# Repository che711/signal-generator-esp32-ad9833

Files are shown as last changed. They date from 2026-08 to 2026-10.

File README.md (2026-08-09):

# DDS Signal Generator — ESP32 + AD9833 with Web UI



A compact, standalone function generator built with an ESP32 microcontroller
and the AD9833 DDS module. Controlled via a rotary encoder or a built-in
web interface, with status shown on a 0.96" SSD1306 OLED screen.
Settings (frequency, waveform, step) are persisted to flash (NVS) and
restored on boot.

---

## Features

| Feature | Details |
|---|---|
| Frequency range | **0.1 Hz – 12 MHz** |
| Frequency resolution | **0.1 Hz** |
| Waveforms | Sine, Triangle, Square, Square/2 |
| Frequency steps | 0.1 Hz / 1 Hz / 10 Hz / 100 Hz / 1 kHz / 10 kHz / 100 kHz / 1 MHz |
| Acceleration | Fast encoder spin = 10× bigger step |
| Web interface | Embedded single-page UI: set frequency/waveform/step, sweep control, curl cheatsheet, live system stats |
| Sweep | Linear / logarithmic frequency sweep, 0.2 s – 1 h, phase-continuous |
| Output enable | Mute button (web/API): DDS sleep, settings kept, state survives reboot |
| Addressing | IP address shown on the OLED at boot; optional mDNS alias `http://dds-gen.local` |
| Persistence | Auto-save to NVS 5 s after the last change + manual save from web UI |
| WiFi watchdog | Automatic reconnect if the connection drops |
| Display | SSD1306 128×64 OLED (I2C) |
| Control | KY-040 rotary encoder (interrupt-driven quadrature decoder) |
| Output | BNC connector (50 Ω) |
| Power | 5V SMPS + LC filter |

---

## Controls

### Rotary encoder

| Action | Result |
|---|---|
| Rotate encoder | Increase / decrease frequency by current step |
| Fast rotation | Step × 10 acceleration |
| Short press | Cycle waveform (SINE → TRI → SQR → SQR/2) |
| Long press (>0.8s) | Cycle frequency step decade |

### Web interface

Open `http://<device-ip>` — the IP is shown on the OLED at boot and printed
to the serial monitor. The page lets you type an exact frequency, pick the
waveform and step, nudge the frequency by the current step, save settings to
memory, and shows live system stats (RSSI, CPU load, RAM, chip temperature,
uptime).

> **mDNS (`http://dds-gen.local`) is a convenience, not a guarantee.** It
> depends on both the client OS and the router: many consumer routers do not
> forward mDNS between wired and wireless clients or across guest/VLAN
> networks, and some block multicast entirely. Windows needs Bonjour or
> Windows 10 1803+; Android support is patchy. If `.local` does not resolve,
> use the IP address — it always works. For scripts and automation, prefer
> the IP (or a DHCP reservation for it) over the hostname.

HTTP API used by the page (usable from scripts too):

| Endpoint | Effect |
| --- | --- |
| `GET /status` | JSON: frequency, waveform, step + system stats |
| `GET /set/freq?v=<hz>` | Set frequency (0.1 – 12 000 000 Hz) |
| `GET /set/wave?v=<name>` | Waveform: `sine`, `tri`, `sqr`, `sqr2` (legacy `0`-`3` accepted) |
| `GET /set/step?v=<size>` | Encoder step, Hz added per click: `0.1`,`1`,`10`,`100`,`1k`,`10k`,`100k`,`1m` (legacy `0`-`7`) |
| `GET /set/out?v=<0\|1>` | Output enable: `0` mutes the DDS (sleep, ~0 V out), `1` restores the selected waveform |
| `GET /save` | Persist current settings to NVS |
| `GET /reboot` | Save settings, then restart the device (`ESP.restart()`) |
| `GET /sweep/start?f0=&f1=&t=&mode=` | Frequency sweep f0 → f1 Hz over `t` seconds, `mode` = `lin` \| `log` |
| `GET /sweep/stop` | Stop sweep mid-run: frequency stays at its current value. A sweep that finishes on its own returns to the pre-sweep frequency |

Every `/set/*` and `/sweep/*` endpoint replies with the same JSON as `/status`,
reflecting the state actually applied (values are clamped to valid ranges).

<details>
<summary><b>curl examples</b> — scripts, Robot Framework, lab automation</summary>

Replace `192.168.1.45` with your device's IP (a DHCP reservation on the
router keeps it stable). `dds-gen.local` also works where mDNS is available.

```bash
DDS=192.168.1.45

# Device state: frequency, waveform, sweep, RSSI, heap, uptime
curl http://$DDS/status

# 10 kHz sine
curl "http://$DDS/set/freq?v=10000"
curl "http://$DDS/set/wave?v=sine"   # sine | tri | sqr | sqr2

# Log sweep 10 Hz -> 100 kHz over 10 s (Bode plot on the scope)
curl "http://$DDS/sweep/start?f0=10&f1=100000&t=10&mode=log"
curl http://$DDS/sweep/stop

# Persist settings to NVS
curl http://$DDS/save
```

Robot Framework setup example:

```robotframework
*** Settings ***
Library    RequestsLibrary

*** Variables ***
${DDS_HOST}    http://192.168.1.45

*** Keywords ***
Set Reference Signal
    [Arguments]    ${freq}    ${wave}=sine
    GET    ${DDS_HOST}/set/freq    params=v=${freq}
    GET    ${DDS_HOST}/set/wave    params=v=${wave}
```

</details>

---

## Hardware

| Component | Description |
|---|---|
| ESP32 DevKit / Super Mini | Main controller |
| AD9833 module | DDS signal generator (SPI) |
| SSD1306 0.96" | OLED display (I2C) |
| KY-040 | Rotary encoder with push button |
| 5V 1A SMPS | Power supply (barrel jack 5.5×2.1 mm) |
| LC filter | Suppresses switching noise from SMPS |
| BNC socket (isolated) | Output connector |
| 100 Ω resistor | Series protection on BNC output |
| RG58 coax cable + BNC plugs | Output cable to oscilloscope |

---

## Wiring

See [wiring.md](wiring.md) for full pin mapping and ASCII schematic.

### Quick reference (ESP32 DevKit)

```
AD9833  CLK  → GPIO 18
AD9833  DAT  → GPIO 23
AD9833  FSYNC→ GPIO  5

OLED    SDA  → GPIO 21
OLED    SCL  → GPIO 22

KY-040  CLK  → GPIO 34
KY-040  DT   → GPIO 35
KY-040  SW   → GPIO 32

AD9833 OUT → [100Ω] → BNC centre
AD9833 GND          → BNC shell
```

All pins are defined in [src/config.h](src/config.h).

---

## Configuration

Before flashing, edit [src/config.h](src/config.h):

```c
#define WIFI_SSID      "YourNetwork"
#define WIFI_PASSWORD  "YourPassword"
#define MDNS_HOSTNAME  "dds-gen"      // optional alias → http://dds-gen.local
```

`MDNS_HOSTNAME` only sets up the optional `.local` alias; the device is
always reachable by IP regardless of whether mDNS resolves on your network.

If WiFi is unavailable the generator still works standalone with the
encoder and OLED.

> Don't commit real WiFi credentials to a public repository.

---

## Build & Flash

### PlatformIO (recommended)

The project uses the [pioarduino](https://github.com/pioarduino/platform-espressif32)
platform (Arduino core 3.x / ESP-IDF 5.x); dependencies are resolved
automatically from `platformio.ini`.

```bash
git clone https://github.com/che711/signal-generator-esp32-ad9833
cd signal-generator-esp32-ad9833
pio run --target upload
pio device monitor
```

### Arduino IDE

1. Install ESP32 board support (arduino-esp32 core 3.x)
2. Install libraries:
   - `AD9833` by Rob Tillaart
   - `U8g2` by olikraus
3. Copy the contents of `src/` into a sketch (rename `main.cpp` to the sketch `.ino`)
4. Select board: **ESP32 Dev Module**
5. Upload

---

## Project Structure

```
signal-generator-esp32-ad9833/
├── src/
│   ├── main.cpp          # Setup & main loop, autosave logic
│   ├── config.h          # Pins, WiFi credentials, timings
│   ├── generator.h/.cpp  # AD9833 wrapper (frequency, waveform, step, NVS)
│   ├── encoder.h/.cpp    # KY-040 encoder (ISR quadrature decoder, debounced button)
│   ├── display.h/.cpp    # SSD1306 OLED screens
│   └── webui.h/.cpp      # WiFi, web server, mDNS, embedded HTML UI
├── wiring.md             # Full wiring guide + ASCII schematic
├── platformio.ini
└── README.md
```

---

## Display Layout

```
┌────────────────────────┐
│ WAVE: SINE         [W] │  ← inverted top bar, [W] = WiFi connected
├────────────────────────┤
│      1.000 kHz         │  ← large frequency (centred)
├────────────────────────┤
│ STP: 1kHz              │
│ NET: MyNetwork         │  ← SSID
│ IP:  192.168.1.45      │  ← web UI address
└────────────────────────┘
```

---

## Output Notes

- AD9833 output amplitude: ~0.65 Vpp (sine/triangle)
- For higher amplitude add an op-amp stage (e.g. AD8051, TL071)
- Square wave output: up to ~3V logic level
- Add a 100 Ω series resistor on the BNC output to prevent damage on short circuit
- Use 50 Ω coax (RG58) for best signal integrity above 1 MHz

---

## Serial Monitor

At 115200 baud the device prints events:

```
[DDS] Booting...
[GEN] Settings loaded from NVS
[GEN] freq=1000.00Hz wave=0 step=4
[WiFi] Connecting to SkyNet....
[WiFi] IP: 192.168.1.45
[mDNS] http://dds-gen.local
[Web] http://192.168.1.45
[DDS] Ready
[ENC] CW → 2000.00 Hz
[BTN] wave → TRI
[Web] freq → 5000.00 Hz
[GEN] Settings saved to NVS
```

---

## License

MIT License — free for personal and commercial use.

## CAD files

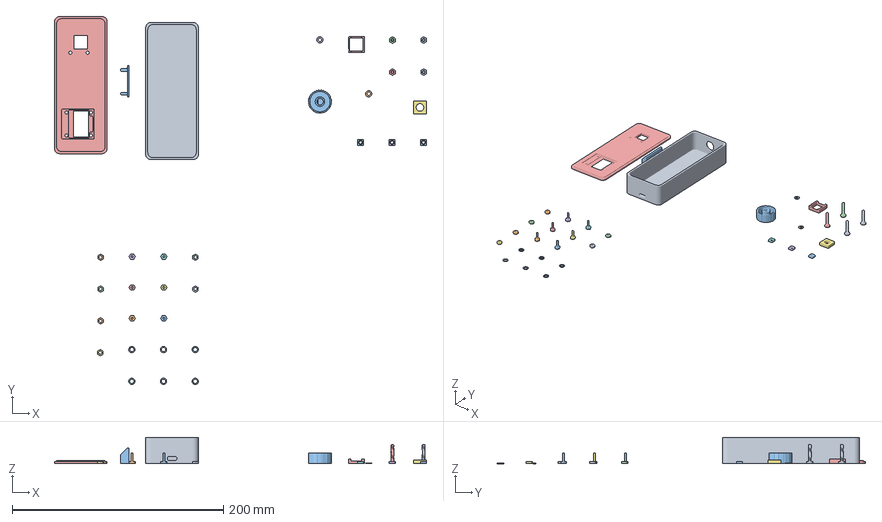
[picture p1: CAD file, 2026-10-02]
docs/Signal_generator_case.3mf
352.3 x 348.4 x 25.0 mm
signal_generator_case.stl_6 x 7
signal_generator_case.stl
signal_generator_case.stl_7 x 7
Amazing Snicket-Bombul (1).stl_2
M3 square nut.stl x 3
Amazing Snicket-Bombul (1).stl_4
M3 washer.stl x 2
webradio_button2.stl
M3x16.stl x 4
Assembly x 6

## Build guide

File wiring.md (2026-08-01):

# Wiring Guide

## Power

```
230V AC → [5V 1A SMPS] → [LC Filter] → 5V rail
                                          │
                              ┌───────────┼──────────────┐
                           ESP32        AD9833        SSD1306
                          (5V/VIN)    (3.3V via      (3.3V via
                                       ESP32)         ESP32)
```

## ESP32 → AD9833 (SPI / HSPI)

| ESP32 Pin | AD9833 Pin | Description |
|---|---|---|
| GPIO 18 | CLK | SPI clock |
| GPIO 23 | DAT | SPI data (MOSI) |
| GPIO  5 | FSYNC | Chip select (CS)  |
| 3.3V | VCC | Power |
| GND | GND | Ground |

> **Note:** AD9833 MISO not used. FSYNC is active-LOW chip select.

## ESP32 → SSD1306 OLED (I2C)

| ESP32 Pin | SSD1306 Pin | Description |
|---|---|---|
| GPIO 21 | SDA | I2C data |
| GPIO 22 | SCL | I2C clock |
| 3.3V | VCC | Power |
| GND | GND | Ground |

> Default I2C address: `0x3C`. Some modules use `0x3D`.
> Check with I2C scanner if display is blank.

## ESP32 → KY-040 Encoder

| ESP32 Pin | KY-040 Pin | Description |
|---|---|---|
| GPIO 34 | CLK | Rotation clock (input-only) |
| GPIO 35 | DT | Rotation data  (input-only) |
| GPIO 32 | SW | Button |
| 3.3V | + | Power |
| GND | GND | Ground |

> GPIO 34 and 35 are **input-only** on ESP32 — no internal pull-up.
> KY-040 has its own pull-up resistors on board, so this is fine.

## BNC Output

| AD9833 Pin | BNC Jack |
|---|---|
| OUT | Centre pin (signal) |
| GND | Shell (ground) |

> Add a **100 Ω series resistor** between AD9833 OUT and BNC centre
> to protect against short circuits.

## Full Schematic (ASCII)

```
                    ┌──────────────────────────────────────┐
   5V ──────────────┤VIN                              GPIO18├──── AD9833 CLK
   GND ─────────────┤GND                              GPIO23├──── AD9833 DAT
                    │                                 GPIO5 ├──── AD9833 FSYNC
                    │                                       │
                    │         ESP32 DevKit            GPIO21├──── OLED SDA
                    │                                 GPIO22├──── OLED SCL
                    │                                       │
                    │                                 GPIO34├──── KY-040 CLK
                    │                                 GPIO35├──── KY-040 DT
                    │                                 GPIO32├──── KY-040 SW
                    │                                       │
                    │   3.3V ─┬──────────────────────       │
                    │         ├── AD9833 VCC                 │
                    │         └── OLED VCC                  │
                    └──────────────────────────────────────┘

AD9833 OUT ──[100Ω]──── BNC centre pin
AD9833 GND ─────────── BNC shell
```

## ESP32 Super Mini Pin Mapping

If using **ESP32 Super Mini** (C3), note it has **no hardware DAC**.
The AD9833 SPI still works — update pin numbers in `src/config.h`:

| Function | DevKit | Super Mini |
|---|---|---|
| SPI SCK  | 18 | 4 |
| SPI MOSI | 23 | 6 |
| SPI CS | 5 | 7 |
| I2C SDA  | 21 | 8 |
| I2C SCL  | 22 | 9 |
| ENC CLK  | 34 | 2 |
| ENC DT | 35 | 3 |
| ENC SW | 32 | 10 |

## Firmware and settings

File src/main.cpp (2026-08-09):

#include <Arduino.h>
#include "generator.h"
#include "encoder.h"
#include "display.h"
#include "webui.h"

// ── Globals ───────────────────────────────────────────────
// The mutex guards SignalGenerator against concurrent access
// from the UI task (core 1) and the web task (core 0)
SemaphoreHandle_t genMutex;

SignalGenerator gen;
Encoder         enc;
Display         disp;
WebUI*          web;   // pointer — constructed after the mutex exists

// ── Web task on core 0 ────────────────────────────────────
void webTask(void* param) {
    web->begin();

    for (;;) {
        web->handle();
        web->checkWiFi();
        web->updateCpuLoad();
        vTaskDelay(pdMS_TO_TICKS(1));   // yield to the scheduler
    }
}

// ── setup ─────────────────────────────────────────────────
void setup() {
    Serial.begin(115200);
    Serial.println("[DDS] Booting...");

    // Create the mutex first — before anything touches gen
    genMutex = xSemaphoreCreateMutex();

    disp.begin();

    // gen.begin() talks to SPI and NVS; the web task is not running yet,
    // so it is safe to call without taking the mutex
    gen.begin();
    enc.begin();

    disp.drawConnecting(WIFI_SSID);

    // Create the WebUI with the mutex and start its task on core 0
    web = new WebUI(gen, genMutex);
    xTaskCreatePinnedToCore(
        webTask,
        "webTask",
        TASK_WEB_STACK,
        nullptr,
        TASK_WEB_PRIORITY,
        nullptr,
        TASK_WEB_CORE
    );

    // Give webTask a moment to bring up WiFi before entering the main loop
    uint32_t waitStart = millis();
    while (!web->isConnected() && millis() - waitStart < WIFI_CONNECT_TIMEOUT_MS + 1000)
        delay(100);

    if (web->isConnected()) {
        disp.drawIP(web->ipAddress());
        delay(3000);
    }

    Serial.println("[DDS] Ready");
}

// ── loop — UI on core 1 ───────────────────────────────────
// Web/WiFi/CPU are serviced by webTask on core 0
static bool     needRedraw = true;
static uint32_t lastSaveMs = 0;
static uint32_t lastDrawMs = 0;

void loop() {
    // Changes made from the web UI must also refresh the OLED and
    // restart the autosave timer
    if (web->consumeChanged()) {
        needRedraw = true;
        lastSaveMs = millis();
    }

    // Sweep: each tick moves the frequency. sweepActive() is read without
    // the mutex — it is a lone bool, worst case is one extra/late take
    if (gen.sweepActive()) {
        if (xSemaphoreTake(genMutex, pdMS_TO_TICKS(5)) == pdTRUE) {
            if (gen.sweepTick(millis())) needRedraw = true;
            xSemaphoreGive(genMutex);
        }
    }

    bool changed = false;
    EncoderEvent ev = enc.poll();

    switch (ev) {
        case ENC_CW: {
            int m = enc.isFast() ? ACCEL_MULTIPLIER : 1;
            if (xSemaphoreTake(genMutex, pdMS_TO_TICKS(10)) == pdTRUE) {
                for (int i = 0; i < m; i++) gen.stepUp();
                Serial.printf("[ENC] CW → %.2f Hz\n", gen.getFrequency());
                xSemaphoreGive(genMutex);
            }
            changed = true;
            break;
        }
        case ENC_CCW: {
            int m = enc.isFast() ? ACCEL_MULTIPLIER : 1;
            if (xSemaphoreTake(genMutex, pdMS_TO_TICKS(10)) == pdTRUE) {
                for (int i = 0; i < m; i++) gen.stepDown();
                Serial.printf("[ENC] CCW → %.2f Hz\n", gen.getFrequency());
                xSemaphoreGive(genMutex);
            }
            changed = true;
            break;
        }
        case ENC_CLICK:
            if (xSemaphoreTake(genMutex, pdMS_TO_TICKS(10)) == pdTRUE) {
                gen.nextWave();
                Serial.printf("[BTN] wave → %s\n", gen.waveLabel());
                xSemaphoreGive(genMutex);
            }
            changed = true;
            break;
        case ENC_LONG_CLICK:
            if (xSemaphoreTake(genMutex, pdMS_TO_TICKS(10)) == pdTRUE) {
                gen.nextStep();
                Serial.printf("[BTN] step → %s\n", gen.stepLabel());
                xSemaphoreGive(genMutex);
            }
            changed = true;
            break;
        default:
            break;
    }

    if (changed) {
        needRedraw = true;
        lastSaveMs = millis();
    }

    // Autosave AUTOSAVE_MS after the last change
    if (lastSaveMs > 0 && millis() - lastSaveMs > AUTOSAVE_MS) {
        if (xSemaphoreTake(genMutex, pdMS_TO_TICKS(50)) == pdTRUE) {
            gen.saveSettings();
            xSemaphoreGive(genMutex);
        }
        lastSaveMs = 0;
    }

    // Redraw at ~30 fps, and only when something changed
    uint32_t now = millis();
    if (needRedraw && now - lastDrawMs > 33) {
        // Snapshot the state under the mutex, then draw without it:
        // sendBuffer() over I2C takes ~22 ms, far too long to hold the
        // mutex while the web task on core 0 may want it.
        String freqStr, waveStr, stepStr;
        if (xSemaphoreTake(genMutex, pdMS_TO_TICKS(10)) == pdTRUE) {
            freqStr = gen.freqLabel();
            // Output disabled — show OFF instead of the waveform
            waveStr = gen.getOutput() ? gen.waveLabel() : "OFF";
            stepStr = gen.stepLabel();
            xSemaphoreGive(genMutex);

            disp.drawMain(
                freqStr,
                waveStr.c_str(),
                stepStr.c_str(),
                web->isConnected(),
                String(WIFI_SSID),
                web->ipAddress()
            );
            lastDrawMs = now;
            needRedraw = false;
        }
        // mutex not acquired → needRedraw stays true, redraw next iteration
    }

    // Short delay so we do not hog core 1
    vTaskDelay(pdMS_TO_TICKS(5));
}

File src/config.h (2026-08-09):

#pragma once

// ── Wi-Fi ─────────────────────────────────────────────────
#define WIFI_SSID      "SkyNet"
#define WIFI_PASSWORD  "password"

// ── Web server ────────────────────────────────────────────
#define WEB_PORT                80
#define MDNS_HOSTNAME           "dds-gen"   // http://dds-gen.local

// ── WiFi watchdog ─────────────────────────────────────────
#define WIFI_RECONNECT_MS       10000
#define WIFI_CONNECT_TIMEOUT_MS 8000

// ── FreeRTOS tasks ────────────────────────────────────────
#define TASK_WEB_STACK        8192
#define TASK_WEB_PRIORITY        1
#define TASK_WEB_CORE            0    // WebUI runs on core 0

// ── Sweep ─────────────────────────────────────────────────
#define SWEEP_TICK_MS      10    // frequency recalc period (100 steps/s)
#define SWEEP_MIN_MS      200    // minimum sweep duration
#define SWEEP_MAX_MS  3600000    // maximum 1 hour

// ── Autosave ──────────────────────────────────────────────
#define AUTOSAVE_MS           5000    // save 5 s after the last change

// ── NVS namespace ─────────────────────────────────────────
#define NVS_NAMESPACE           "ddsgen"

// ── SPI (AD9833) ──────────────────────────────────────────
#define GEN_SCK_PIN             18
#define GEN_MOSI_PIN            23
#define GEN_CS_PIN               5

// ── I2C (SSD1306) ─────────────────────────────────────────
#define OLED_SDA_PIN            21
#define OLED_SCL_PIN            22
#define OLED_ADDR               0x3C

// ── KY-040 encoder ────────────────────────────────────────
#define ENC_CLK_PIN             34
#define ENC_DT_PIN              35
#define ENC_SW_PIN              32

// ── Encoder timing ────────────────────────────────────────
#define BTN_DEBOUNCE_MS   20    // ms of stable level (KY-040 bounces 5-30 ms)
#define LONG_PRESS_MS    800
#define ACCEL_THRESHOLD   80    // ms between detents to count as fast rotation
#define ACCEL_MULTIPLIER  10    // step x 10 while spinning fast

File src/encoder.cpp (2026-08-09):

#include "encoder.h"

volatile int32_t Encoder::_s_delta = 0;
volatile uint8_t Encoder::_s_state = 0;
portMUX_TYPE     Encoder::_s_mux   = portMUX_INITIALIZER_UNLOCKED;

// ─────────────────────────────────────────────────────────
// Table-driven quadrature decoder.
//
// Both pins (CLK+DT) are interrupt-driven, so edges are never missed
// while the OLED redraw blocks I2C for tens of milliseconds.
//
// The table index is 4 bits: (previous state << 2) | current state.
// Valid transitions yield ±1, invalid ones (bounce, missed edge) yield 0.
// That gives direction and software debounce at once — no delay() needed.
// ─────────────────────────────────────────────────────────
static const int8_t QUAD_TABLE[16] = {
     0, -1, +1,  0,
    +1,  0,  0, -1,
    -1,  0,  0, +1,
     0, +1, -1,  0
};

// KY-040: 4 quadrature transitions per detent (one click)
#define TICKS_PER_DETENT 4

void IRAM_ATTR Encoder::_isr() {
    uint8_t s = (uint8_t)((digitalRead(ENC_CLK_PIN) << 1)
                         | digitalRead(ENC_DT_PIN));
    portENTER_CRITICAL_ISR(&_s_mux);
    _s_state = (uint8_t)(((_s_state << 2) | s) & 0x0F);
    _s_delta += QUAD_TABLE[_s_state];
    portEXIT_CRITICAL_ISR(&_s_mux);
}

Encoder::Encoder()
    : _accum(0), _lastDetentMs(0), _fast(false),
      _lastRaw(HIGH), _stableState(HIGH), _lastEdgeMs(0),
      _btnPending(false), _btnPressMs(0)
{}

void Encoder::begin() {
    // GPIO 34/35 are input-only — NO internal pull-ups available!
    // The KY-040 module has its own pull-ups on CLK/DT; a bare encoder
    // needs external 10k resistors to 3.3 V.
    pinMode(ENC_CLK_PIN, INPUT);
    pinMode(ENC_DT_PIN,  INPUT);
    pinMode(ENC_SW_PIN,  INPUT_PULLUP);

    _s_state = (uint8_t)((digitalRead(ENC_CLK_PIN) << 1)
                        | digitalRead(ENC_DT_PIN));
    attachInterrupt(digitalPinToInterrupt(ENC_CLK_PIN), _isr, CHANGE);
    attachInterrupt(digitalPinToInterrupt(ENC_DT_PIN),  _isr, CHANGE);
}

// The button is polled first: _pollRotation() looks at its debounced state
// to suppress spurious ticks generated while clicking
EncoderEvent Encoder::poll() {
    EncoderEvent ev = _pollButton();
    if (ev != ENC_NONE) return ev;
    return _pollRotation();
}

EncoderEvent Encoder::_pollRotation() {
    // Atomically take what the ISR has accumulated
    portENTER_CRITICAL(&_s_mux);
    int32_t d = _s_delta;
    _s_delta = 0;
    portEXIT_CRITICAL(&_s_mux);

    // While the button is held the shaft twitches mechanically — drop those
    // spurious ticks so a click does not shift the frequency
    if (_stableState == LOW || _btnPending) { _accum = 0; return ENC_NONE; }

    _accum += d;

    int dir = 0;
    if      (_accum >=  TICKS_PER_DETENT) { _accum -= TICKS_PER_DETENT; dir = +1; }
    else if (_accum <= -TICKS_PER_DETENT) { _accum += TICKS_PER_DETENT; dir = -1; }
    else return ENC_NONE;

    uint32_t now = millis();
    _fast = ((now - _lastDetentMs) < ACCEL_THRESHOLD);
    _lastDetentMs = now;

    // If the direction comes out inverted, swap the CLK/DT wires
    // or flip the signs here.
    return (dir > 0) ? ENC_CW : ENC_CCW;
}

// Time-based debounce: any raw edge restarts the timer, and a level is
// accepted only after BTN_DEBOUNCE_MS of stability. A single re-check would
// land inside the KY-040 bounce window (5-30 ms) and lose the press.
// No blocking delay() involved.
EncoderEvent Encoder::_pollButton() {
    int raw = digitalRead(ENC_SW_PIN);
    uint32_t now = millis();

    if (raw != _lastRaw) {          // raw edge — restart the filter
        _lastRaw = raw;
        _lastEdgeMs = now;
        return ENC_NONE;
    }

    if (now - _lastEdgeMs < BTN_DEBOUNCE_MS) return ENC_NONE;

    if (raw != _stableState) {      // level is stable and has changed
        _stableState = raw;
        if (raw == LOW) {           // confirmed press
            _btnPressMs = now;
            _btnPending = true;
        } else if (_btnPending) {   // confirmed release
            _btnPending = false;
            uint32_t held = now - _btnPressMs;
            return (held >= LONG_PRESS_MS) ? ENC_LONG_CLICK : ENC_CLICK;
        }
    }
    return ENC_NONE;
}

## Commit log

2026-04-05 fix from copilot to display.h/cpp
    [config.h, main.cpp]
2026-07-19 fix wrong rotate issue
    [config.h, encoder.cpp, generator.cpp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]
2026-08-01 fix: races + atomic flag, add CI
    [main.cpp]
2026-08-01 feat: output enable (mute) — web toggle, /set/out API, OLED OFF indicator, NVS persist
2026-08-02 fix: wifi stability — disable modem sleep, autoReconnect, log disconnect reasons
2026-08-02 feat: soft reboot — /reboot endpoint + button in System card (saves settings first)
2026-10-01 added docs/ directoty and the drawing of the generator's case
    [signal_generator_case.stl]
2026-10-01 remove the previous drawing of the case and added a newest one
    [Signal_generator_case.3mf, signal_generator_case.stl]
2026-10-16 added .stl to the project
